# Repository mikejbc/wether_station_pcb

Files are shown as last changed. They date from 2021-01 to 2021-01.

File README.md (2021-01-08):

# Schemat Stacji Pogodowej wraz z projektem płytki PCB

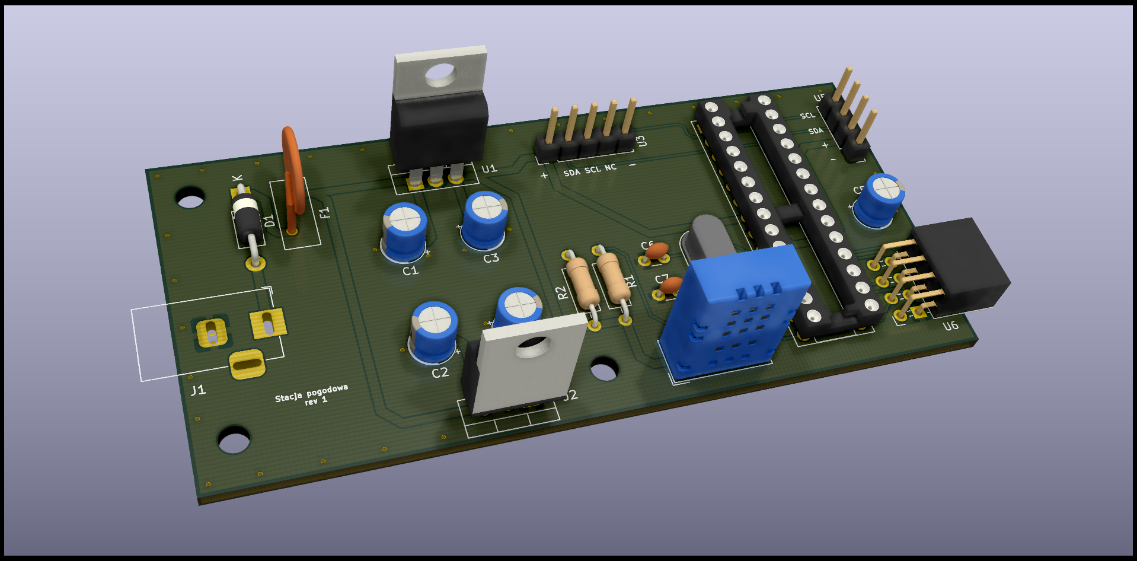
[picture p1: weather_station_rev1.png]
PCB


Cechy projektu:

+ Wykonany w Kicad
+ Oparty na mikrokontrolerze Atmega328
+ Wykorzystuje Czujnik temperatury i wilgotności DHT 22
+ ...

## Źródła:

+ https://howtomechatronics.com/tutorials/arduino/arduino-wireless-weather-station-project/

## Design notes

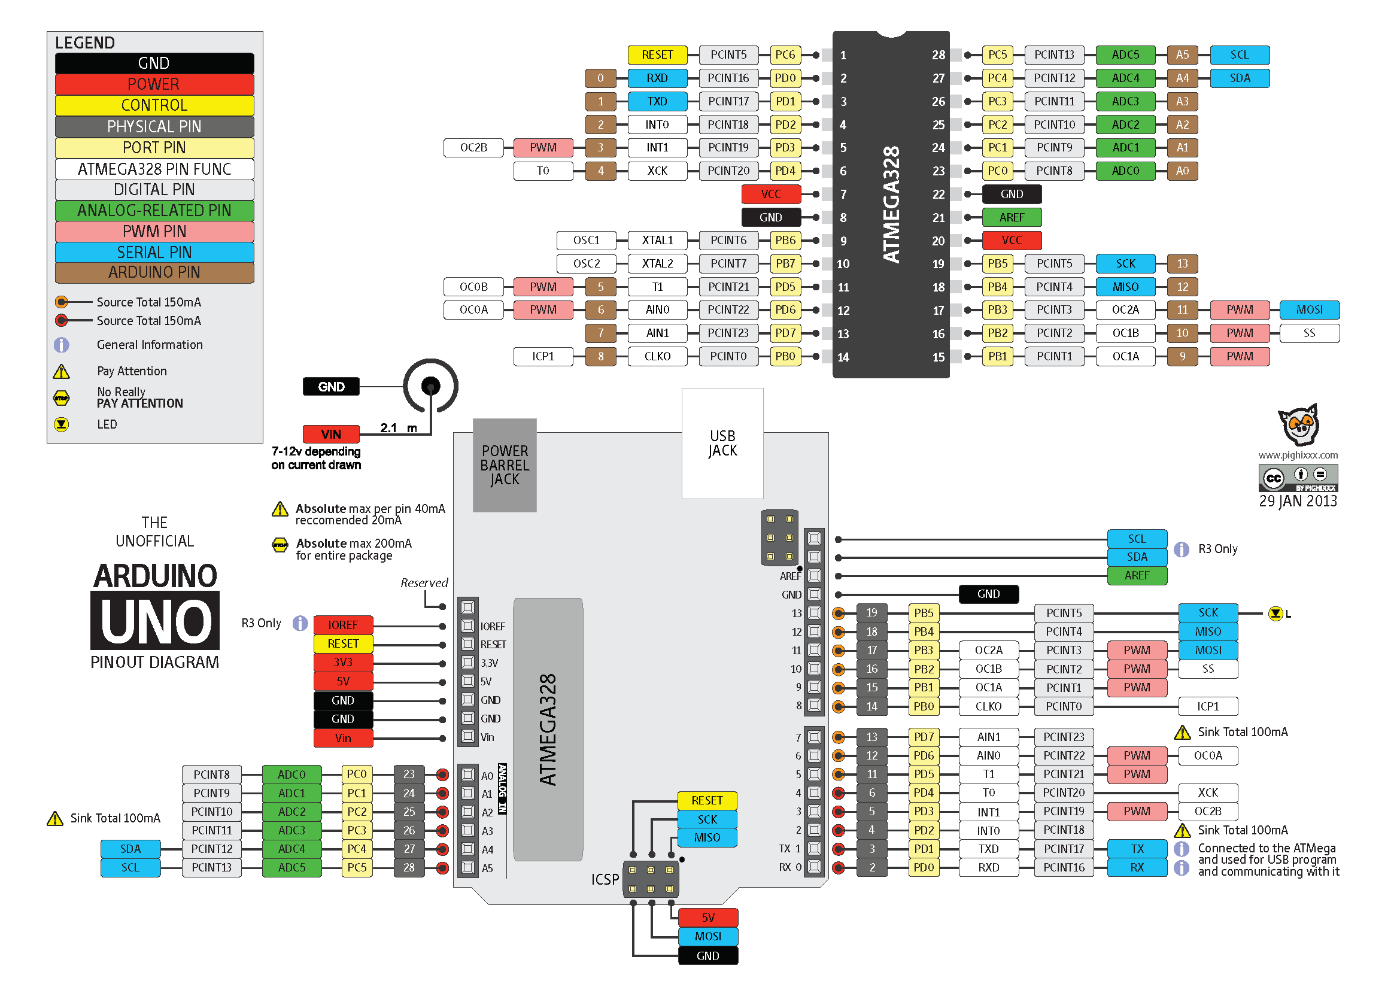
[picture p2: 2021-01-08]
atmel-etiket-mcu-sticker-atmega328-pinout-arduino-uno-pinout.png

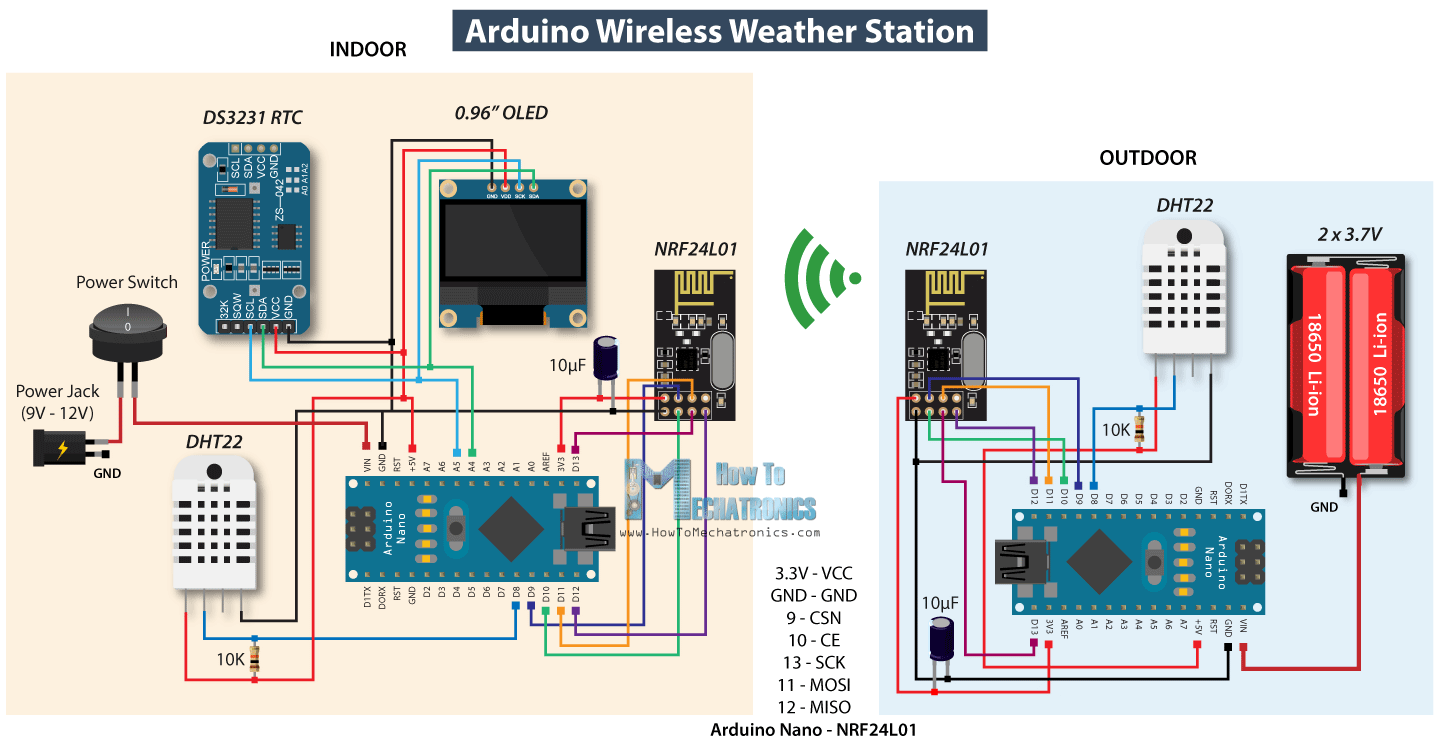
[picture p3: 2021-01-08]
Arduino-Wireless-Weather-Station-Circuit-Diagram.png

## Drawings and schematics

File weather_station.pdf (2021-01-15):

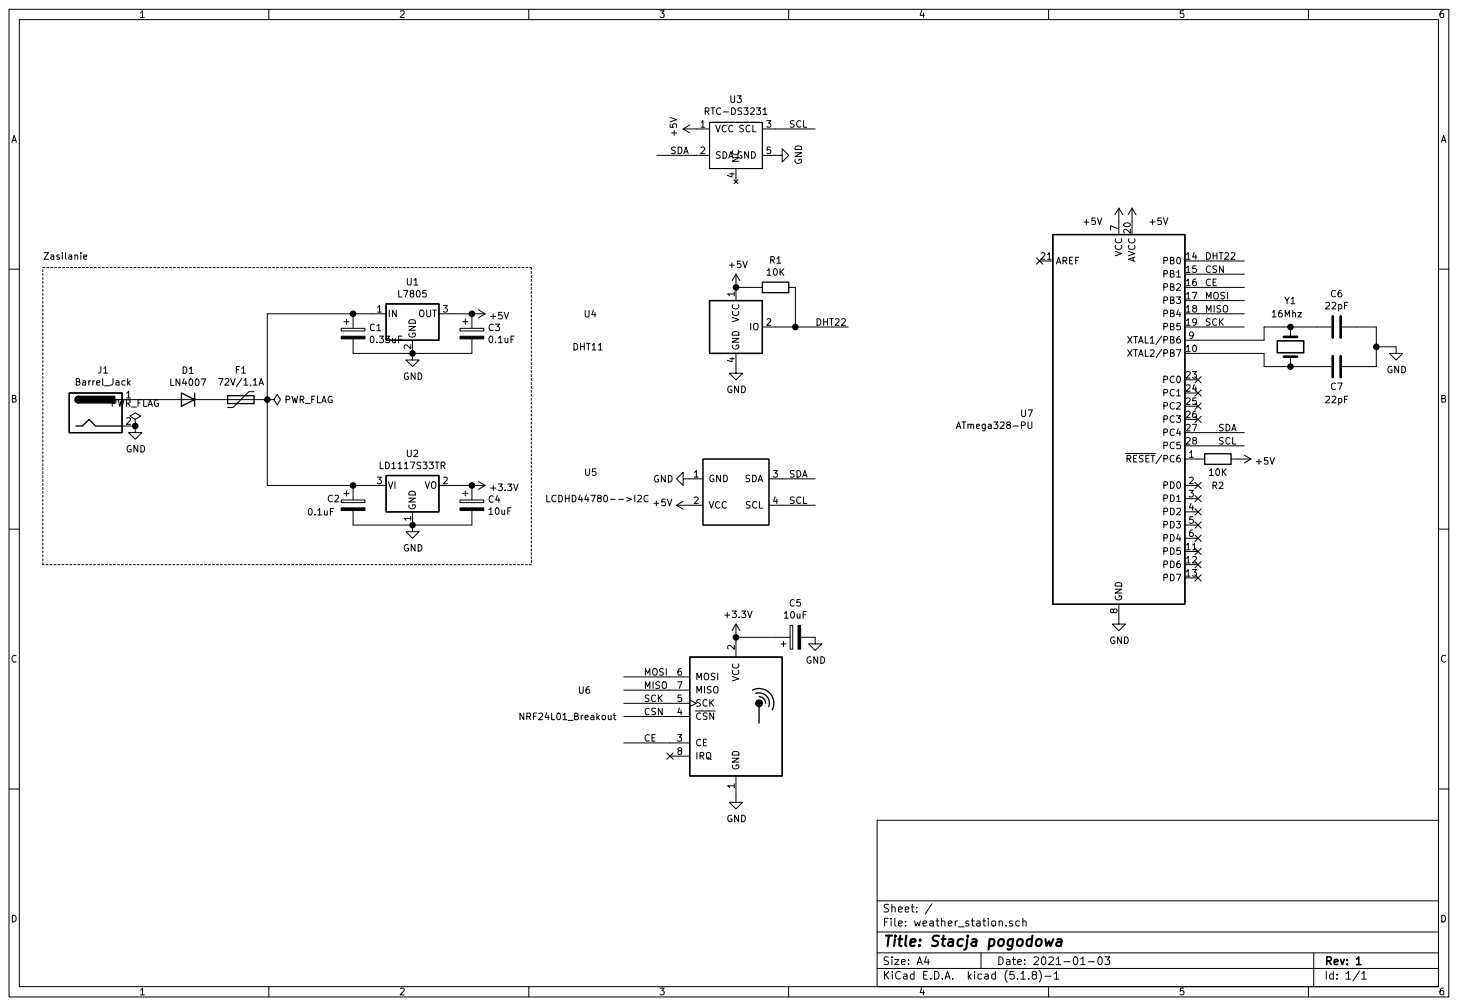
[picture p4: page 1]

SCK MISO MOSI SCL SDA

2 CE 3 CSN 4 SCK 5 MOSI 6 MISO 7

File: weather_station.sch Sheet: /
Id: 1/1 Title: Stacja pogodowa

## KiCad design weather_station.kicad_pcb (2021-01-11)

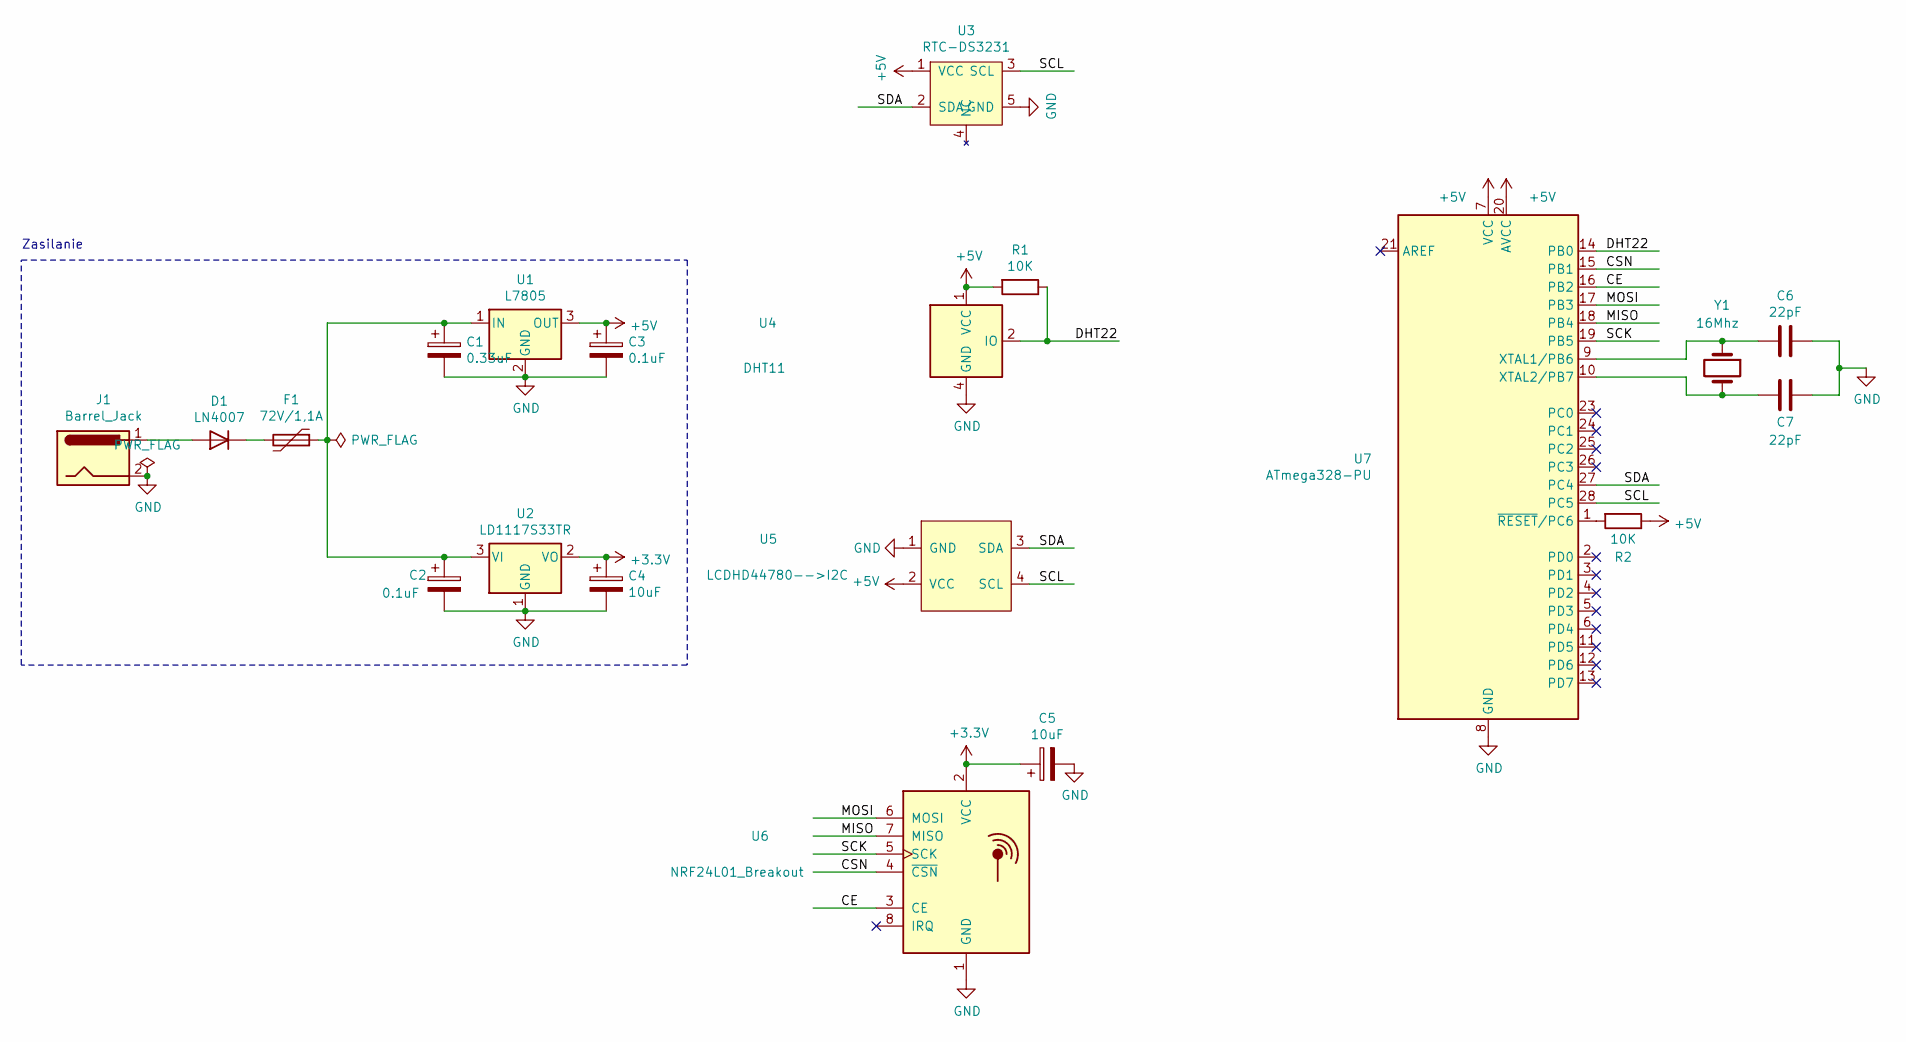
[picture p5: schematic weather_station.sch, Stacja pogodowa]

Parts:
C1: 0.33uF; CP_Radial_D5.0mm_P2.00mm
C2, C3: 0.1uF; CP_Radial_D5.0mm_P2.00mm
C4, C5: 10uF; CP_Radial_D5.0mm_P2.00mm
C6, C7: 22pF; C_Disc_D3.0mm_W1.6mm_P2.50mm
D1: LN4007; D_DO-41_SOD81_P10.16mm_Horizontal
F1: 72V/1,1A; Fuse_BelFuse_0ZRE0016FF_L9.9mm_W3.8mm
J1: Barrel_Jack; BarrelJack_Horizontal
R1, R2: 10K; R_Axial_DIN0207_L6.3mm_D2.5mm_P10.16mm_Horizontal
U1: L7805; TO-220-3_Vertical
U2: LD1117S33TR; TO-220-3_Vertical
U3: RTC-DS3231; PinHeader_1x05_P2.54mm_Vertical
U4: DHT11; Aosong_DHT11_5.5x12.0_P2.54mm
U5: LCDHD44780-->I2C; PinHeader_1x04_P2.54mm_Vertical
U6: NRF24L01_Breakout; NRF24-horizontal-pin-socket
U7: ATmega328-PU; DIP-28_W7.62mm_Socket
Y1: 16Mhz; Crystal_HC49-4H_Vertical

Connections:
+3V3: C4.1, C5.1, U2.2 (VO), U6.2 (VCC)
+5V: C3.1, R1.2, R2.1, U1.3 (OUT), U3.1 (VCC), U4.1 (VCC), U5.2 (VCC), U7.7 (VCC), U7.20 (AVCC)
/CE: U6.3 (CE), U7.16 (PB2)
/CSN: U6.4 (~CSN), U7.15 (PB1)
/DHT22: R1.1, U4.2 (IO), U7.14 (PB0)
/MISO: U6.7 (MISO), U7.18 (PB4)
/MOSI: U6.6 (MOSI), U7.17 (PB3)
/SCK: U6.5 (SCK), U7.19 (PB5)
/SCL: U3.3 (SCL), U5.4 (SCL), U7.28 (PC5)
/SDA: U3.2 (SDA), U5.3 (SDA), U7.27 (PC4)
GND: C1.2, C2.2, C3.2, C4.2, C5.2, C6.1, C7.1, J1.2, U1.2 (GND), U2.1 (GND), U3.5 (GND), U4.4 (GND), U5.1 (GND), U6.1 (GND), U7.8 (GND), U7.22 (GND)
unnamed: C1.1, C2.1, F1.1, U1.1 (IN), U2.3 (VI)
unnamed: C6.2, U7.9 (XTAL1/PB6), Y1.1
unnamed: C7.2, U7.10 (XTAL2/PB7), Y1.2
unnamed: D1.1 (K), F1.2
unnamed: D1.2 (A), J1.1
unnamed: R2.2, U7.1 (~RESET~/PC6)

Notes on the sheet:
Zasilanie

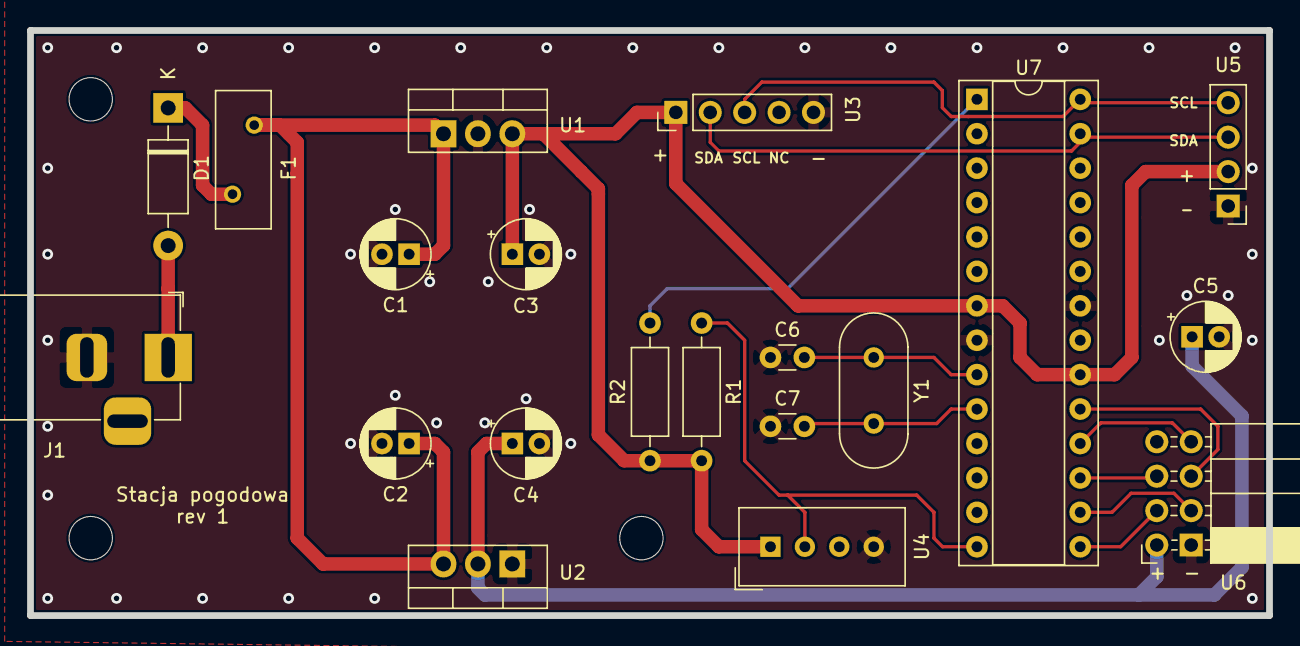
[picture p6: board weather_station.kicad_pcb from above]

Board: 2 copper layers, 91.4 x 43.2 mm, 20 parts (0 on the bottom side), 17 nets.

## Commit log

2021-01-08 stacja pogodowa
    [weather_station.kicad_pcb, weather_station.sch]
2021-01-08 Zdjęcie pcb w README
2021-01-10 Poprawiona płytka (konektor NRF24 oraz otwory na śrubki)
    [weather_station.kicad_pcb, weather_station.sch]
2021-01-10 Zmiana otworów na śruby z M2 na M3
    [weather_station.kicad_pcb]
2021-01-11 Wersja wysłana do produkcji
    [weather_station.kicad_pcb]
